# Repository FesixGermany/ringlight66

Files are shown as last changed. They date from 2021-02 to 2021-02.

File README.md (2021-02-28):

# ringlight66  

Ringlight for microscope with 16 LEDs running at 24V at 60-70mA in total (30-35mA per row of LEDs).  
Inner dia 47.2mm, outer dia 66mm.  

LEDs used are Nichia NFSW036DT which could be brighter with more current but I wanted to have more even illumination so I went with more LEDs at lower current instead of a few very bright ones at higher current. This also brings down the heat dissipation of the current limiting resistors and the LEDs.  

These LEDs are no longer available but others can be used with similar package such as PLCC-2. Forward voltage of LEDs will be different so the current limiting resistors might have to be changed.  
Also important to note is, that some LEDs have additional pads for heat dissipation in the middle. These would short the pads so such can not be used.  

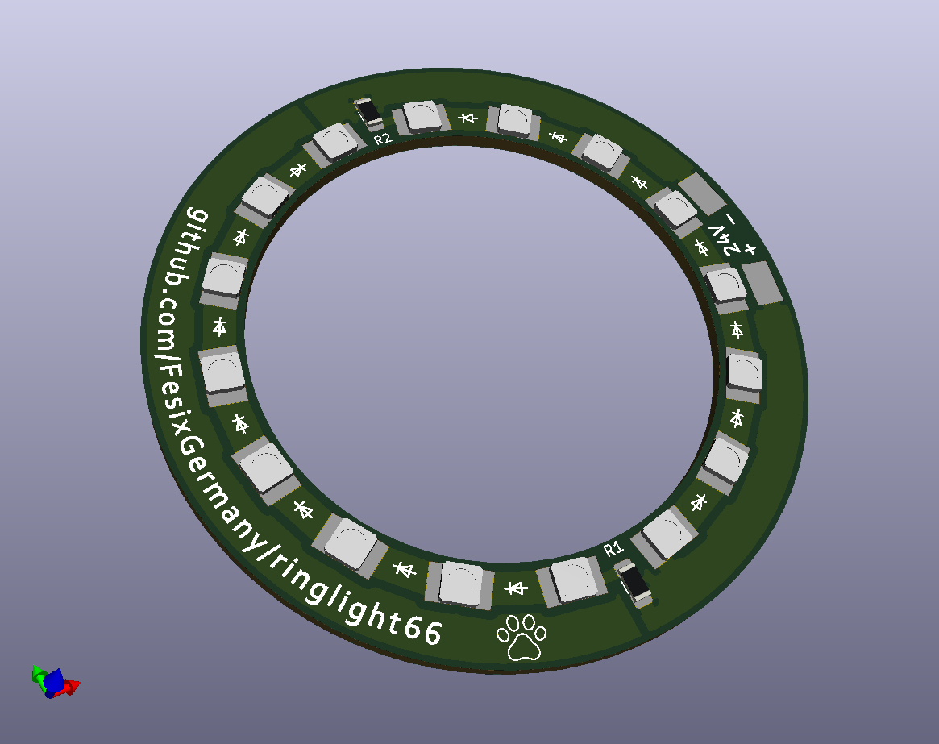
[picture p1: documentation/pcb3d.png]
Image of Board


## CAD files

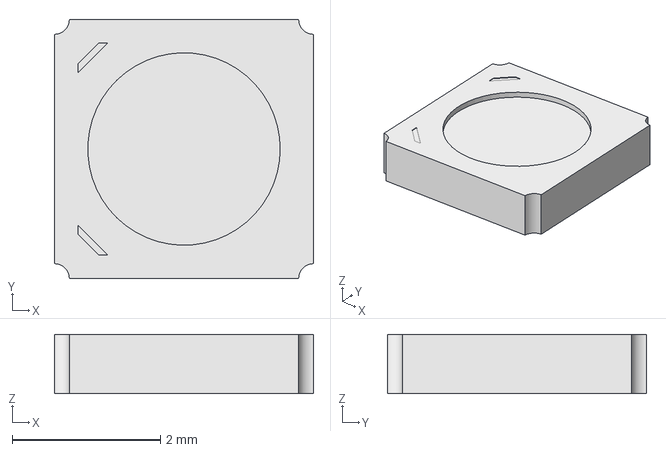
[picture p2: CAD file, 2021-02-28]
schematic and board files/3D/LED.step
3.50 x 3.50 x 0.8 mm

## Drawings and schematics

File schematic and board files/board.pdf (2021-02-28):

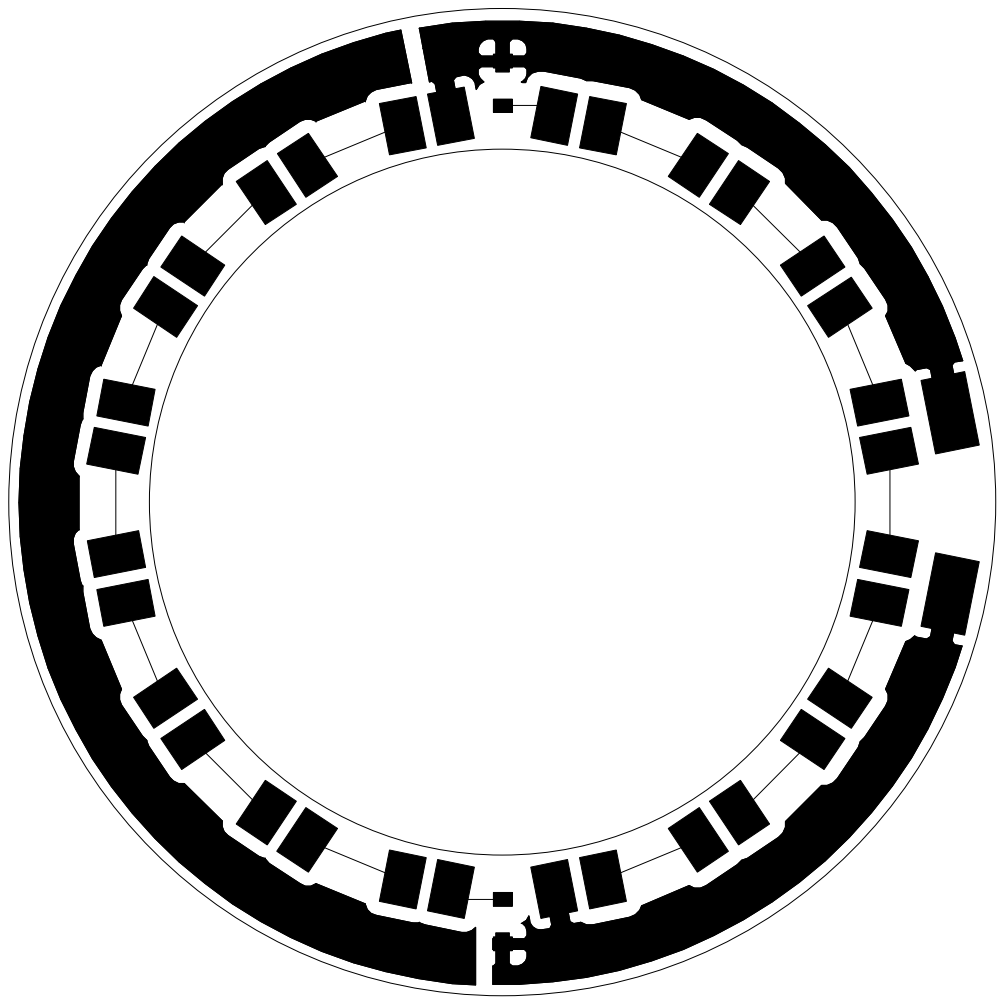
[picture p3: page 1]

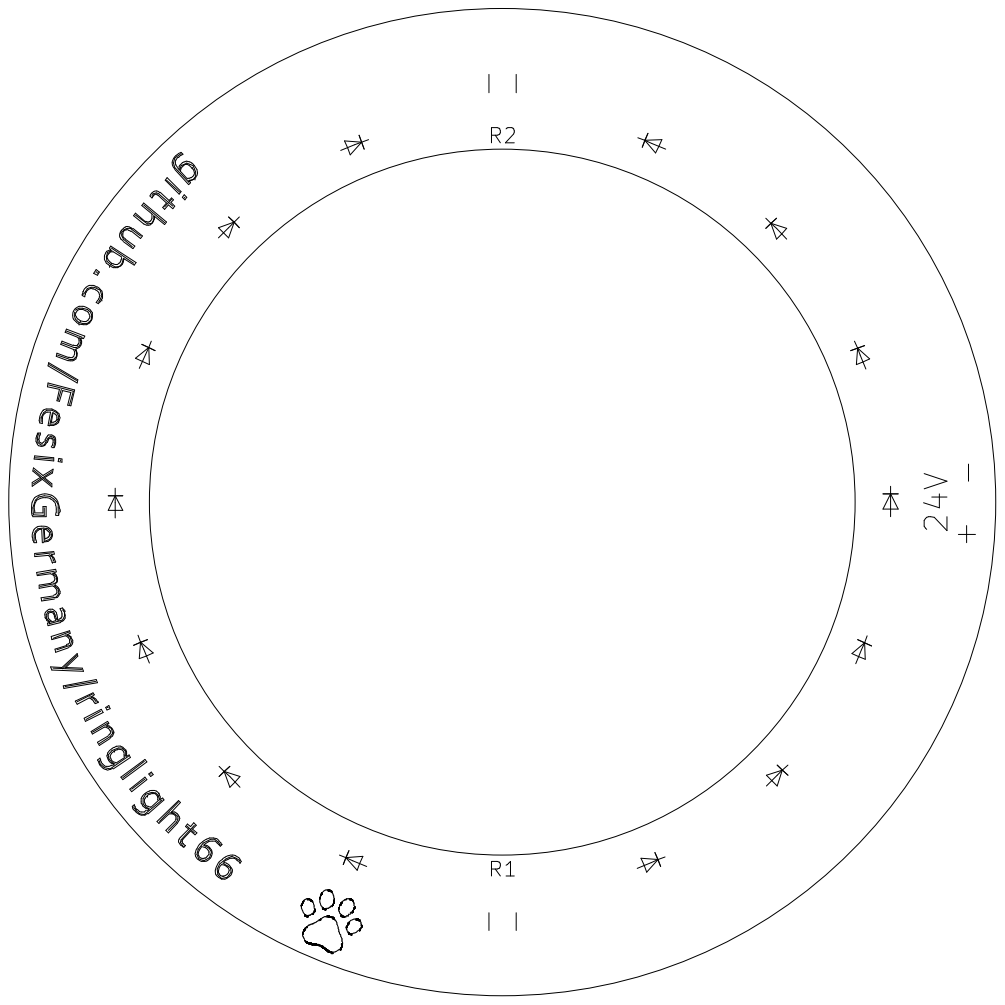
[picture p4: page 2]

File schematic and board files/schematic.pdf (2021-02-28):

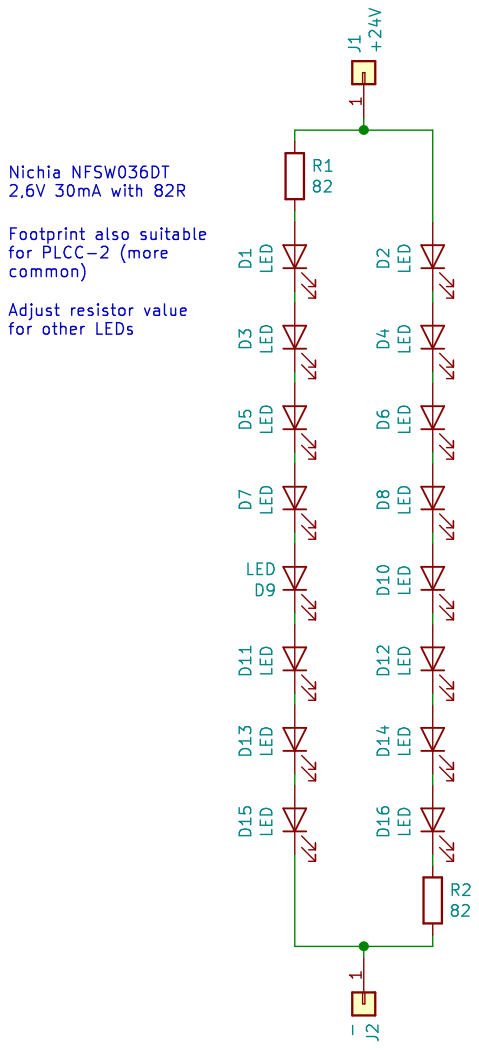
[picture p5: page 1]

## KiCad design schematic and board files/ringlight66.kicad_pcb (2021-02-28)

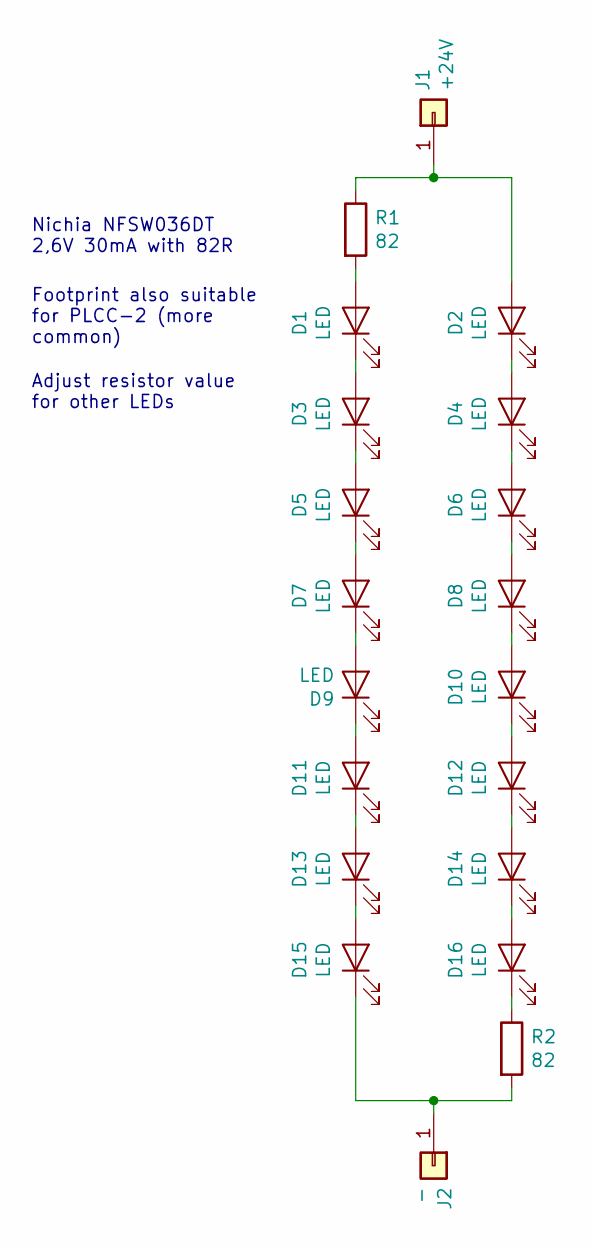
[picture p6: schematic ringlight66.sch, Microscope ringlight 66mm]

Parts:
D1, D2, D3, D4, D5, D6, D7, D8, D9, D10, D11, D12, D13, D14, D15, D16: LED; LED_3535
J1: +24V; SolderWirePad_1x01_SMD_5x10mm
J2: -; SolderWirePad_1x01_SMD_5x10mm
R1, R2: 82; R_1206_3216Metric_Pad1.42x1.75mm_HandSolder

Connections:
unnamed: D1.1 (K), D3.2 (A)
unnamed: D1.2 (A), R1.2
unnamed: D2.1 (K), D4.2 (A)
unnamed: D2.2 (A), J1.1, R1.1
unnamed: D3.1 (K), D5.2 (A)
unnamed: D4.1 (K), D6.2 (A)
unnamed: D5.1 (K), D7.2 (A)
unnamed: D6.1 (K), D8.2 (A)
unnamed: D7.1 (K), D9.2 (A)
unnamed: D10.1 (K), D12.2 (A)
unnamed: D8.1 (K), D10.2 (A)
unnamed: D11.1 (K), D13.2 (A)
unnamed: D9.1 (K), D11.2 (A)
unnamed: D12.1 (K), D14.2 (A)
unnamed: D13.1 (K), D15.2 (A)
unnamed: D14.1 (K), D16.2 (A)
unnamed: D15.1 (K), J2.1, R2.2
unnamed: D16.1 (K), R2.1

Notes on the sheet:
Nichia NFSW036DT 2,6V 30mA with 82R
Footprint also suitable for PLCC-2 (more common)
Adjust resistor value for other LEDs

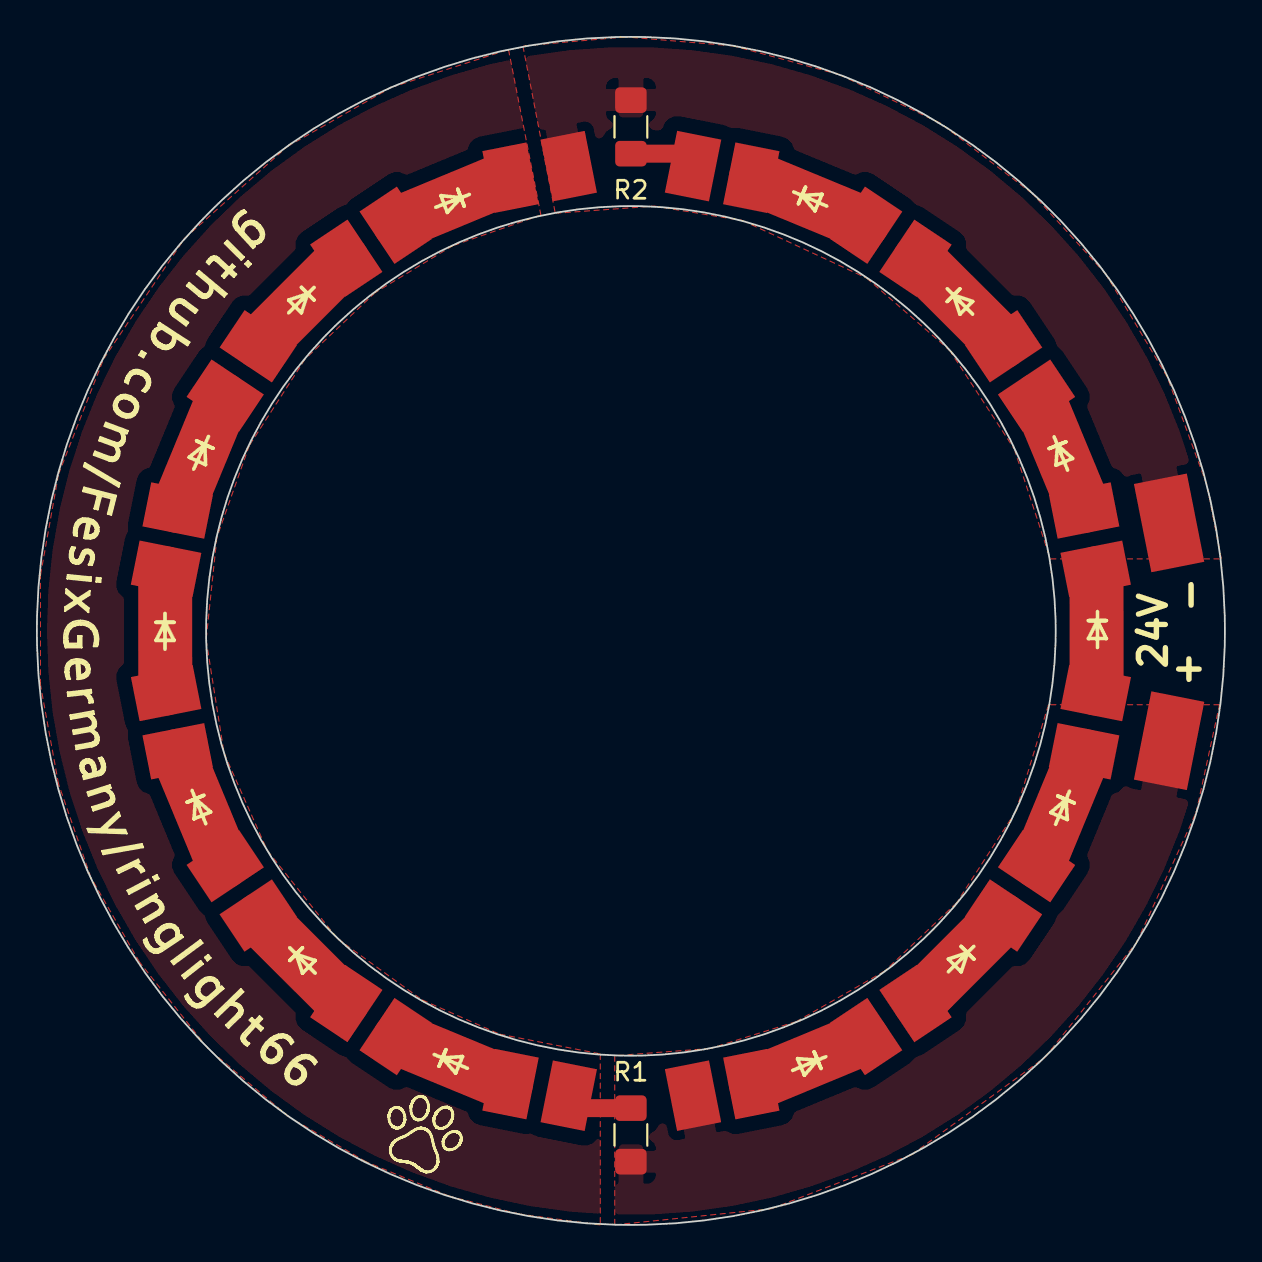
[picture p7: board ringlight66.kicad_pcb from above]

Board: 2 copper layers, 66.0 x 66.0 mm, 20 parts (0 on the bottom side), 18 nets.
